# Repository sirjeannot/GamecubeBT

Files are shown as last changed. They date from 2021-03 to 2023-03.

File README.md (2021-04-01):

# GamecubeBT

An arduino based bridge to connect a bluetooth PS3 controller to the Gamecube.
Homemade Wavebirds, because the TV is too far from the couch.

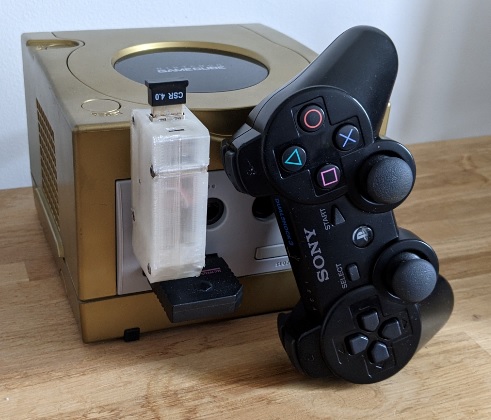
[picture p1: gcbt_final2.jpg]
done


This is nothing new, this is using two existing libraries : Nicohoods Nintendo to handle controller data sent to the GameCube, and PS3BT to use a PS3 controller.

### Current status / Not Working / ToDo
* **working!**
* **stick sensitivity ok!**
* adapt the code for PS4 controller : this is only about using PS4BT functions rather than PS3BT.
* support Powera Gamecube Switch controller

### Limitations
* no rumble support
* inputs can be missed in case of mashing of buttons

### Bill of material
For this project I used components I had gathering dust : Arduino Nano, BT dongle TBW-107UB.
* 16MHz Arduino (Nintendo library limitation) : 5E
* USB Host Shield : 5E
* USB Bluetooth2.1+EDR dongle or better : 8E (works fine with cheap bluetooth 4.0 dongle)
* 3.3V / 5V level logic level converter : 3E
* Gamecube cable extention : 5E
Prices are rounded up, should be less than 26E.

### USB HOST hardware
The cheap knockoff I ordered isn't well documented. I strongly recommend you do a continuity check to find out which pins connect to the MAX3421E : VCC (5V), VL (3.3V), INT, RST, SS, MISO, MOSI, SCLK, GND. The link to the datasheet is in the documentation section.

Mine looks like this, yours may be different.
This board directly connects VCC to VL. Once trace shall be cut or there will be power supply issues.

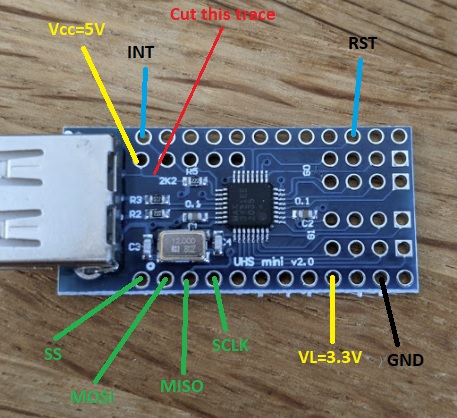
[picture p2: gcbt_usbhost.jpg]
usb host pinst


### Wiring
First check which cable matches the following pins on the controller cable (male end).

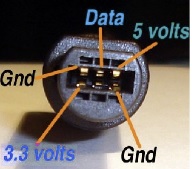
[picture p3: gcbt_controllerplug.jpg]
gamecube plug pins
 (image borrowed from https://hackaday.io/project/162348)

Wiring of the SS pin of the USB Host may be different depending on the Arduino board used. It is either D10 or D3.

| Arduino | USB Host | Gamecube |
| --- | --- | --- |
| GND | GND | GND (both) |
|  | 3.3V | 3.3V |
| 5V | Vcc | 5V |
| D3 | INT | |
| D8 | | DATA* |
| D10 | SS | |
| D11 | MOSI | |
| D12 | MISO | |
| D13 | SCLK | |
| RST | RST | |

Data logic on the Gamecube is 3.3V, D8 pin shall be routed through a logic level 5V to 3.3V.
| Logic Level | Arduino | Gamecube |
| --- | --- | --- |
| GND | GND | GND |
| LV | | 3.3V |
| HV | | 5V |
| HV1 | D8 | |
| LV1 | | DATA |

### Controller layout
This is the default layout I chose. Feel free to change it : the switch position of the left stick and d-pad is sometimes not the best choice.

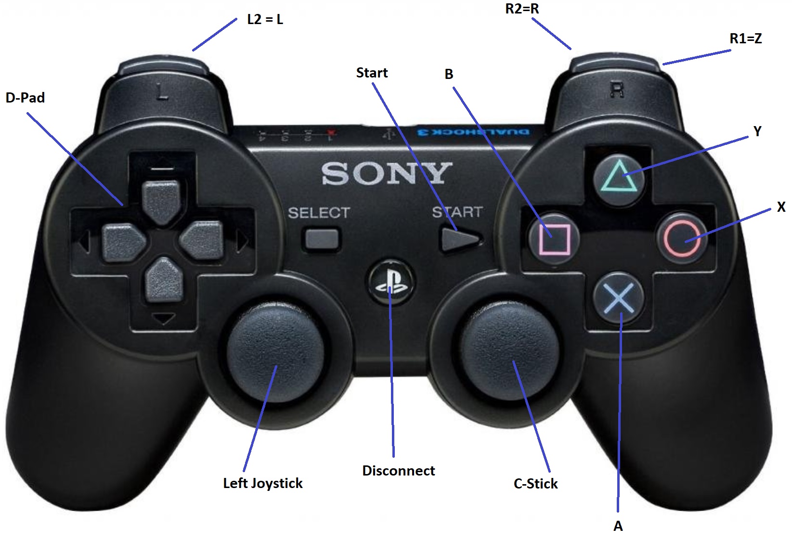
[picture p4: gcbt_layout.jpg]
layout


### Enclosure

The enclosure comes in two parts, located in the stl subfolder.
They should be printed with layers = 0.2mm. Place the outside face on the bed to print without support. 
To close the box, use 4xm3 screws, 2.2cm length.
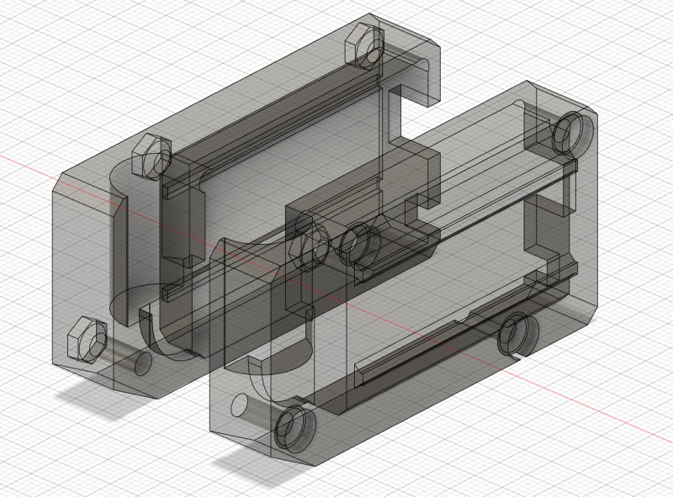
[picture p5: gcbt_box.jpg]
model


### Demo
youtube video (https://youtu.be/wYV4qaWRAow)

### Documentation / References
* Nico Nintendo Library : https://github.com/NicoHood/Nintendo
* USB HOST v2.0 : https://github.com/felis/USB_Host_Shield_2.0
* MAX3421E : https://datasheets.maximintegrated.com/en/ds/MAX3421E.pdf
* DIY Wireless Gamecube Controller : https://hackaday.io/project/162348

### Q&A
* Why let the usb dongle stick out? --> This is part of the pairing process : the controller will need to be connected to the usb plug to get the MAC address of the BT dongle for the PS3 controller.
* Why not use an ESP32 which has integrated bluetooth? --> 1. I didn't have any spare esp32 when I did that project. 2. The Nintendo library from Nicohood has time sensitive routines coded in AVR assembly for 16MHz clocks. I didn't want to review timings as it was supposed to be a simple straightforward project to reuse old arduinos.
* It already exists, BlueRetro does it better! --> Yes it does, it supports more consoles, more controllers and more ports. My intent was to use simple and 'in my inventory' items. Also BlueRetro does it the right way by allocating one core for Bluetooth and one core for Wire. This project does both on a single core with a 10x lower clockspeed (but only one controller, can't do everything!). That may be a lead to support the Powera Gamecube Switch controller which was the initial goal of the project.

### Coverage
* Hackaday : https://hackaday.com/2021/03/29/bluetooth-ps3-controllers-modernize-the-nintendo-gamecube/

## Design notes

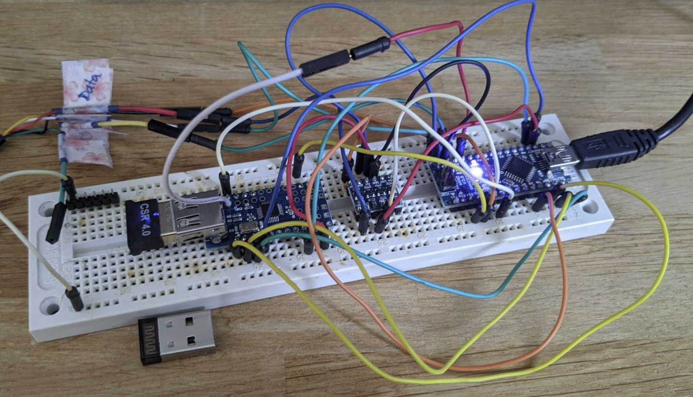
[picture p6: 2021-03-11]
gcbt_breadboard.jpg

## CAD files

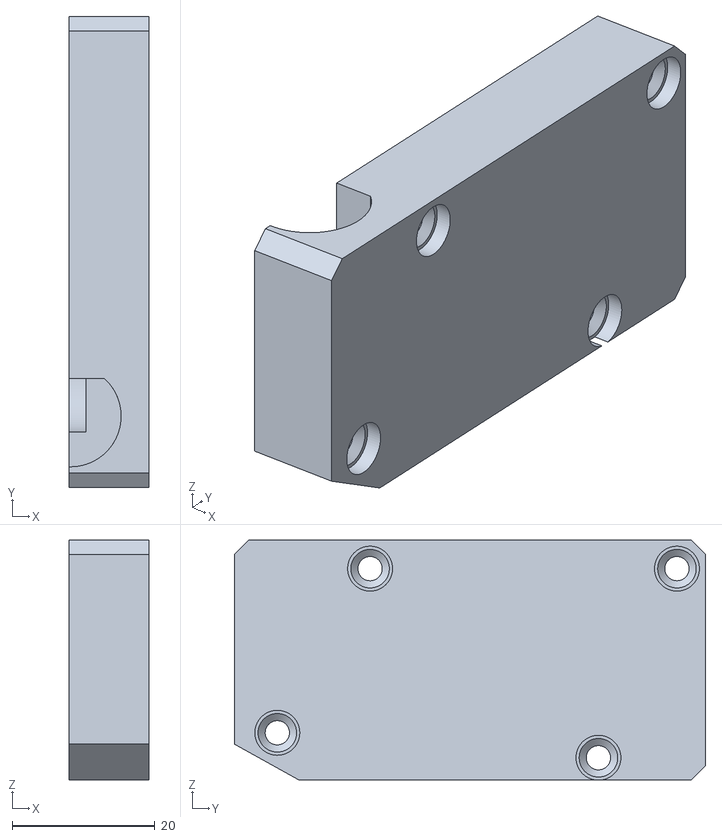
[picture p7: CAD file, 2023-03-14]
stl/box_left.stl
11.2 x 66.0 x 33.6

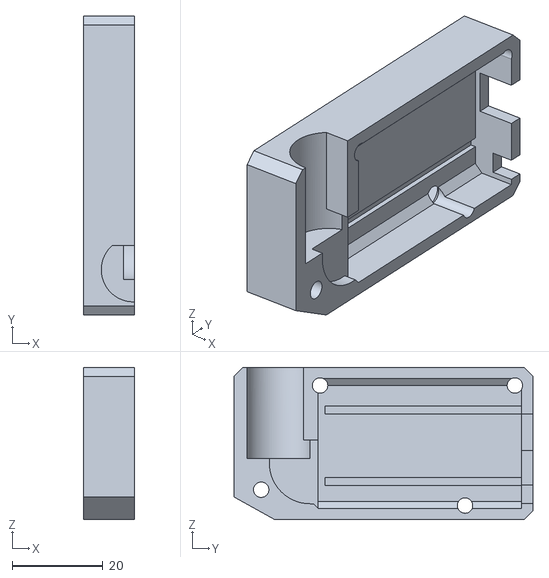
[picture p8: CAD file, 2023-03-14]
stl/box_right.stl
11.2 x 66.0 x 33.6

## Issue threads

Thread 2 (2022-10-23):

stl files are wrong

supermanknievel, 2022-10-23:
the stl files for the case are way to small to print   need the correct one  what size should it be

sirjeannot, 2023-02-15:
hello,

yes, scale them up by x10 in all dimensions. I used the wrong unit during export.

Closed 2023-03-14.

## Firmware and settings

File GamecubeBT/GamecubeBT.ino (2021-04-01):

/*
   Gamecube Controller using PS3 Controller.
   https://github.com/sirjeannot/GamecubeBT/

   Based on Nicohood Nintendo library
   https://github.com/NicoHood/Nintendo
   Based on USBHOST library
   https://github.com/felis/USB_Host_Shield_2.0
   Interrupt howto
   https://www.instructables.com/Arduino-Timer-Interrupts/
*/

//timer for gamecube interrupt
#define TIMER1_MAX 70
//scale for analog axis
#define SCALE 0.785

//Nintendo gamecube bus
#include "Nintendo.h"
//PS3 controller bt
#include <PS3BT.h>
#include <usbhub.h>
#include <SPI.h>

//Define a Gamecube Controller and a Console
CGamecubeConsole GamecubeConsole1(8);
CGamecubeController GamecubeController1(7);
Gamecube_Data_t d = defaultGamecubeData;

USB Usb;
USBHub Hub1(&Usb); // Some dongles have a hub inside
BTD Btd(&Usb); // You have to create the Bluetooth Dongle instance like so
PS3BT PS3(&Btd); // This will just create the instance
//PS3BT PS3(&Btd, 0x00, 0x15, 0x83, 0x54, 0x00, 0x72); // This will also store the bluetooth address - this can be obtained from the dongle when running the sketch
//#define pinLed LED_BUILTIN

//reset function for failed usb host init
void(* resetFunc) (void) = 0;

ISR(TIMER1_COMPA_vect) {
  GamecubeConsole1.write(d);
}

void setup()
{
  //pinMode(pinLed, OUTPUT);
  GamecubeController1.read();
  //Serial.begin(250000);

  while (Usb.Init() == -1) {
    Serial.print(F("\r\nOSC did not start"));
    delay(500);
    resetFunc();
  }
  Serial.println(F("\r\nPS3 Bluetooth Library Started"));

  cli();
  //set timer1 interrupt at 1Hz
  TCCR1A = 0;// set entire TCCR1A register to 0
  TCCR1B = 0;// same for TCCR1B
  TCNT1 = 0;//initialize counter value to 0
  // set compare match register for 1hz increments
  OCR1A = TIMER1_MAX;// = (70*10^6) / (1*1024) - 1 (must be <65536)
  // turn on CTC mode
  TCCR1B |= (1 << WGM12);
  // Set CS10 and CS12 bits for 1024 prescaler
  TCCR1B |= (1 << CS12) | (1 << CS10);
  // enable timer compare interrupt
  TIMSK1 |= (1 << OCIE1A);
  sei();//allow interrupts
}

void loop()
{
  Usb.Task();
  if (PS3.PS3Connected || PS3.PS3NavigationConnected) {
    //out of deadzone
    if (PS3.getAnalogHat(LeftHatX) > 147 || PS3.getAnalogHat(LeftHatX) < 107 || PS3.getAnalogHat(LeftHatY) > 147 || PS3.getAnalogHat(LeftHatY) < 107 || PS3.getAnalogHat(RightHatX) > 137 || PS3.getAnalogHat(RightHatX) < 117 || PS3.getAnalogHat(RightHatY) > 137 || PS3.getAnalogHat(RightHatY) < 117) {
      d.report.xAxis = PS3.getAnalogHat(LeftHatX) * SCALE + 28;
      d.report.yAxis = (255 - PS3.getAnalogHat(LeftHatY) * SCALE) - 27; //yaxis values are inverted
      d.report.cxAxis = PS3.getAnalogHat(RightHatX) * SCALE + 28;
      d.report.cyAxis = (255 - PS3.getAnalogHat(RightHatY) * SCALE) - 27 ; //yaxis values are inverted
    }
    //in deadzone
    else {
      d.report.xAxis = 128;
      d.report.yAxis = 128;
      d.report.cxAxis = 128;
      d.report.cyAxis = 128;
    }
    d.report.left = PS3.getAnalogButton(L2);
    d.report.left > 200 ? d.report.l = 1 : d.report.l = 0 ;
    d.report.right = PS3.getAnalogButton(R2);
    d.report.right > 200 ?  d.report.r = 1 :  d.report.r = 0 ;
    d.report.x = PS3.getButtonPress(CIRCLE);
    d.report.y = PS3.getButtonPress(TRIANGLE);
    d.report.a = PS3.getButtonPress(CROSS);
    d.report.b = PS3.getButtonPress(SQUARE);
    d.report.dup = PS3.getButtonPress(UP);
    d.report.dright = PS3.getButtonPress(RIGHT);
    d.report.ddown = PS3.getButtonPress(DOWN);
    d.report.dleft = PS3.getButtonPress(LEFT);
    d.report.z = PS3.getButtonPress(R1);
    d.report.start = PS3.getButtonPress(START);
    if (PS3.getButtonClick(PS))
      PS3.disconnect();
  }
  //GamecubeConsole1.write(d); //disabled, run by timer1
}

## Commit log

2021-03-14 updated to user timer1 interrupts
2021-03-14 working.
    fixed disconnects & input lag. y axes inverted.
    [GamecubeBT.ino]
2023-03-14 scaling correction
    [box_left.stl, box_right.stl]
